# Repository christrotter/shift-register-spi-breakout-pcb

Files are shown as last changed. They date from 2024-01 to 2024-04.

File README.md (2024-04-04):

# Overview
Tested and working as of 20240403! \o/

A simple? breakout board that provides 32 matrix pins (_16 row and 16 column_) over SPI - using only 6 MCU pins!
Designed for and tested in QMK - requires a custom matrix.  Expects you to be using ROW2COL diode orientation.

This document includes:
- Understanding shift registers (_rather extensive_)
- Matrix-inator PCB notes
- Matrix-inator schematic detail
- Sample code

There's also a [STEP file](/matrix-inator-rev2.step) for testing fitment on your models.

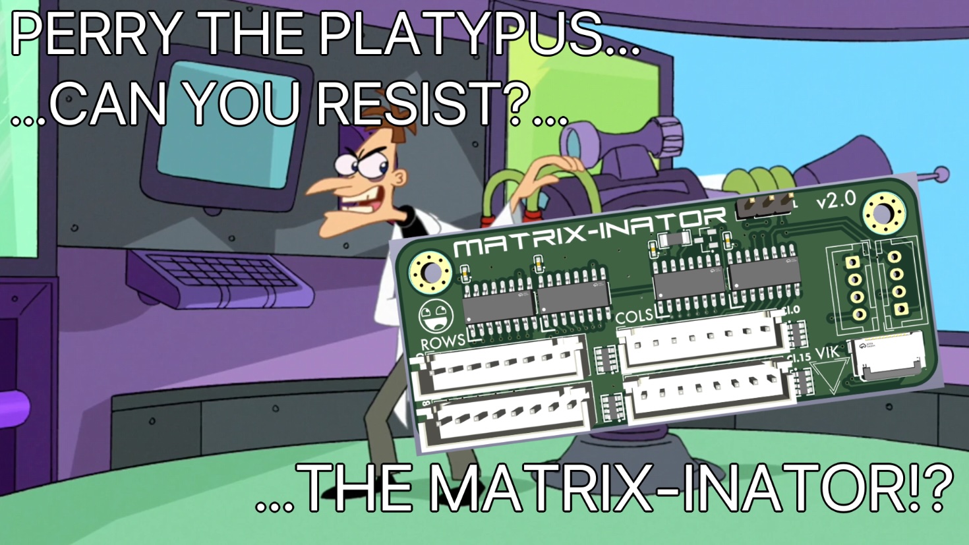
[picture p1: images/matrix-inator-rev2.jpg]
Perry...Perry the platypus?!

*-inate your keyboard matrix with the Matrix-inator!*

# Implementation notes
- The code examples are QMK-centric and utilize Chibios bits and bobs
- The latch header is redundant - **should always be connected ("enable latch")**.  If there's a future rev I will remove it.

# Why not 74HC165 shift registers?
There are 74HC589 supply issues, why not use the 74HC165 shift register?  Because *the 165 cannot share the SPI bus*, and QMK only allows you - at present - to utilize a single SPI bus.  You could use the 165 if you also included a tri-state buffer (e.g. 74HC1G125-Q100).  The 589 has that built-in.

# Usage
After soldering/hooking this into your keyboard, you'll need to add the custom matrix code to your QMK keyboard.

Between the [QMK docs](https://docs.qmk.fm/#/custom_matrix?id=custom-matrix) and this readme, you should have enough to get off the ground.

#### Connection
You can use the included 2x4 2.54mm pin header arrangement (_fits up to JST-XH headers_), or a [VIK-format 12-pin@0.5mm pitch FPC cable](https://github.com/sadekbaroudi/vik)
- _Power_: GND, 3.3V
- _Any GPIO_: Row CS, Col CS, Latch
- _SPI_: Clock/MISO/MOSI from the same SPI bus
- _rows and cols_: 2.54mm headers, do what you want here.

#### PCBA (PCB assembly)
If you want to order this, the gerbers are included in the latest [Github release](https://github.com/christrotter/shift-register-spi-breakout-pcb/releases/latest).

I seem to recall there being a silly part showing up that shouldn't have been (_like a logo or something_), but everything important came through.

Headers not part of the BOM, only the complicated and fiddly stuff.

#### Additonal parts you'll need
See the latest [Github release](https://github.com/christrotter/shift-register-spi-breakout-pcb/releases/latest) if you need all the parts.
- (_optional_) some flavour of 2.54mm-spaced headers
- 12-pin @ 0.5mm pitch FPC cable of sufficient length and a keyboard with a VIK port
  - (_or_) 2x 4-pin 2.54mm headers
- M3 hardware or some way of mounting the pcb to your model

#### Latch header notes
There's a 3-pin header labeled **Enable Latch**.

> *It will need to have pins 2 & 3 connected for the latch to work.* 

This is a development leftover.  Future revisions will not have it.

# Understanding shift registers
In order to understand shift registers, it's very important to understand how QMK's matrix scanning works.  And, of course, to understand that, you need to read their docs:
- https://docs.qmk.fm/#/understanding_qmk
- https://docs.qmk.fm/#/how_keyboards_work
- https://docs.qmk.fm/#/how_a_matrix_works

This doc is my simplification of the topic.

> **NOTE**: for the sake of illustration, you can use the idea that HIGH = "pin has voltage" and LOW = "pin is grounded". 

## Matrix scanning, tl;dr: 
1. Start matrix scan
2. Loop over each row pin.  on each loop, set this row pin HIGH (_all others LOW_) and then check **ALL** col pins for a reciprocal HIGH.
3. Build a `new_matrix_maybe` object with the result of each row iteration
4. Compare `live_matrix` with `new_matrix_maybe` - if differences, replace `live_matrix` with `new_matrix_maybe`
5. End matrix scan loop
(_and now QMK does everything else_)

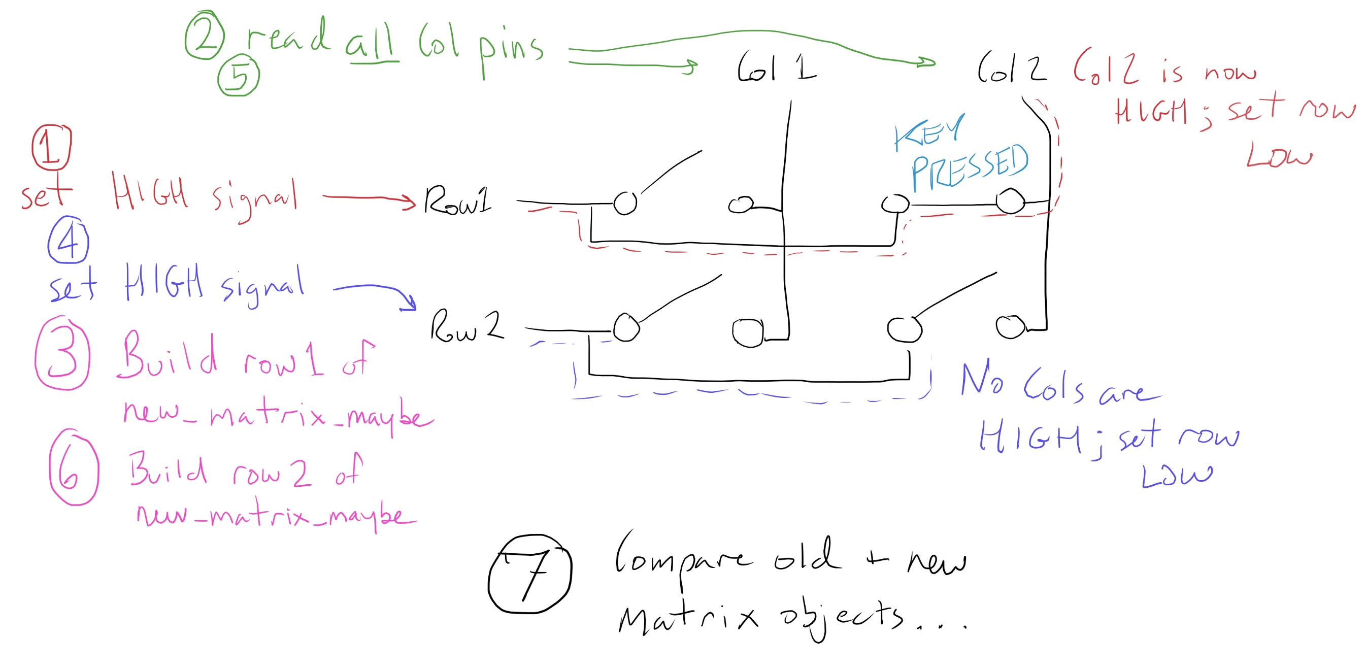
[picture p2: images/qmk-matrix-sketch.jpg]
Matrix basic


> Have you ever looked at the QMK console messages for 'scan rate'?  Well that number is how many times per second the above matrix scan runs (_simplifying_).

> **NOTE**: I use the term 'row pin' in this document only to keep things simple - QMK and shift registers don't work the same way as if you had GPIOs configured as row pins.

### why ROW2COL and not COL2ROW?
I have been working on integrating the Cyboard flex-pcb system into my latest build, and Cyboard is ROW2COL.  I'm sure the design could be refactored to handle any config method.  Indeed, if you use `direct pin` (_where the switches connect to ground_) you can have an even simpler shift register and matrix design.

If you're used to COL2ROW, it's, for all intents and purposes, identical, just flip rows & cols around.

## Pseudo matrix scan code
This is (_mostly_) not real code.
```c
bool matrix_scan_custom(matrix_row_t current_matrix[]) {
    static matrix_row_t temp_matrix[ROWS_COUNT] = {0};
    for (uint8_t row = 0; row < (ROWS_COUNT); row++) {
        set_row_high(row_pin);              // this row pin is set HIGH; any keypresses will show as HIGH on col pins
        cycle_latch_pin(latch_pin);         // prepares the col shift registers for data shipping; shift register magic
        col_state = spi_receive(col_pin);   // ship col state from shift register into the MCU as col_state
        new_matrix_maybe[row] = col_state;  // update this row of the new_matrix_maybe object with the returned col state
    }
    bool matrix_has_changed = compare_matrix(new_matrix_maybe, live_matrix);
    if (matrix_has_changed) {
        update_active_matrix(new_matrix_maybe);
    }
    return matrix_has_changed;
}
```

## Shift register magic explained
> Obviously shift registers are not magic and are completely understandable - I use the word 'magic' as an entertaining literary device.  Covering all of the detail is just too much scope for this doc.  If I can understand it, you can, too!

There are two types of registers being used here:
- 74HC589: get the HIGH/LOW state of the data pins and return via SPI ([74HC589 datasheet](https://www.onsemi.com/pdf/datasheet/mc74hc589a-d.pdf))
- 74HC595: set the data pins to a HIGH/LOW state as per instructions sent via SPI ([74HC595 datasheet](https://www.onsemi.com/pdf/datasheet/mc74hc595a-d.pdf))

The shift registers each have 8 "data" pins and a bunch of SPI/functionality pins.  
- The 589 reads 8 bits of data from the data pins in parallel, and then ships them out serially.
- The 595 takes 8 bits of data serially and applies it to the data pins in parallel.

Said another way, one accepts data from our code (_595_), the other provides data for our code (_589_).

Remember that there are no perfect solutions, and you're always making tradeoffs.  Recall we have a GPIO constraint...the shift registers get us more "GPIO" at the cost of complication.  That complication comes in the form of a parallel->serial->parallel flow.

- "Hay, row_shift_register, set a row pin to HIGH, please"
- "Okay, while that row is HIGH; col_shift_register, check all your pins - any HIGH?"
(_repeat for every row pin_)

Consider the matrix sketch above...instead of using GPIOs to send the signals to rows/cols, we use magical shift registers.

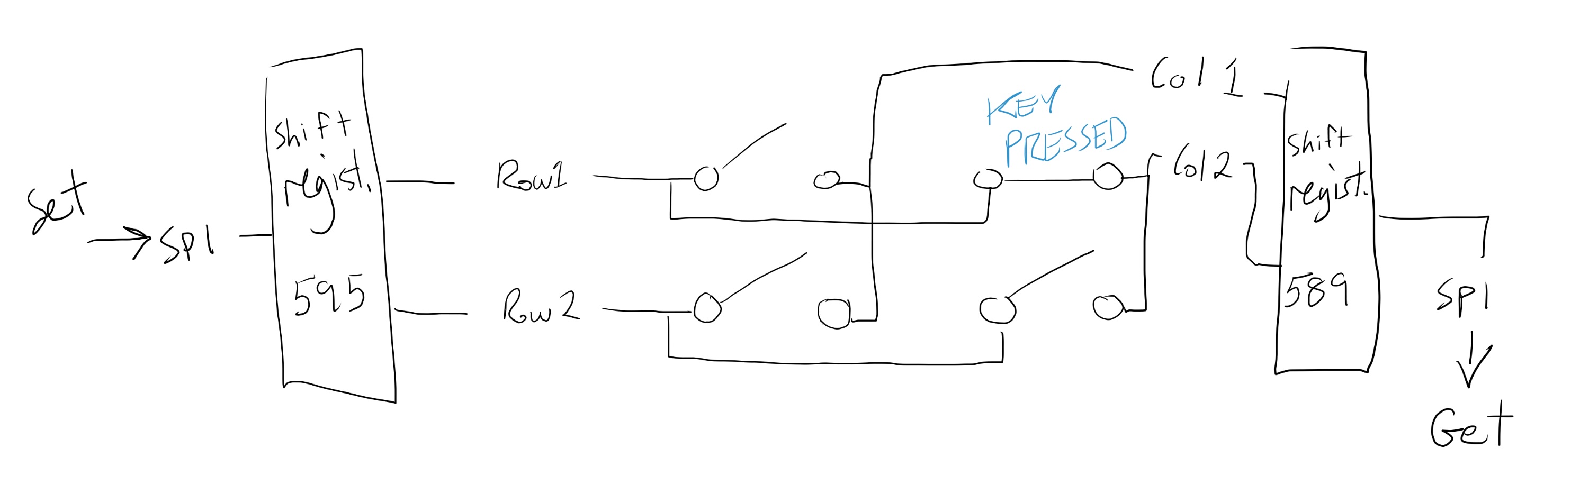
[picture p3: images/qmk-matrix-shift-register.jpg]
Matrix using shift registers


While there are some nuances for handling resets and the like - for keyboard applications you endlessly loop over rows, so no need for resets or anything fancy on the row_shift_registers.  But, the col_shift_registers handle ordered data...and if you handle the data incorrectly, your matrix results are sporadic at best.

So you need to understand a tiny bit about the 589 shift registers.

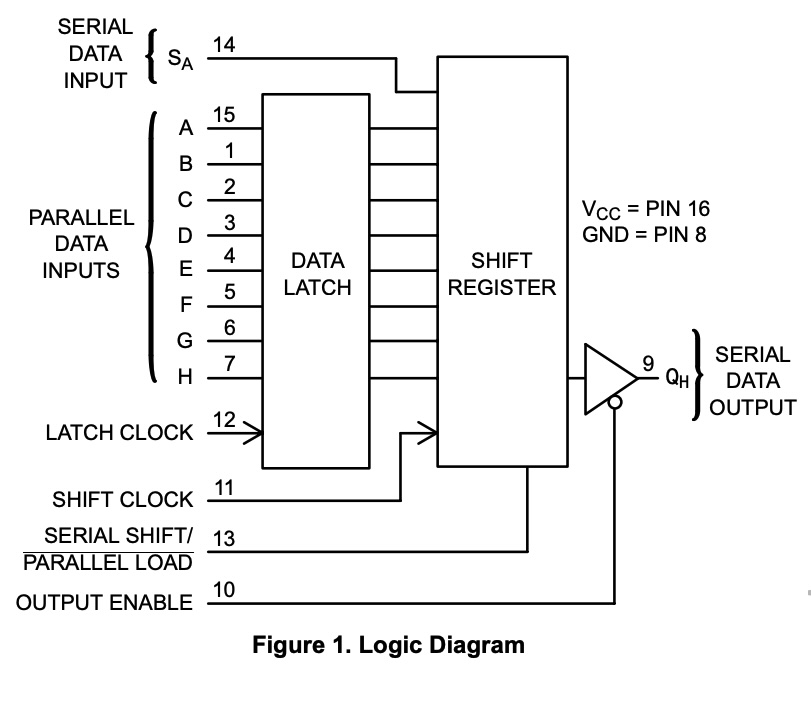
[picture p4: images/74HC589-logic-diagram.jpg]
Logic of 589


Simply put - the data we need is stored in the `data latch`.  To retrieve it via SPI, we need to tell the register to transfer it from the `data latch` into the `shift register`, which has a small amount of memory for serial operations.  Once in the next 'serial transfer' part of the clock cycling, the data in the `shift register` will be pulled out over SPI.

> Remember, the 595 works on effectively the same principles, just the reverse flow.

### Deep magicks
Each shift register has 8 bits (_1 byte_) - the data pins are digital, 0 or 1 - so you can understand what is going on in your digital matrix (_HIGH/LOW_) by polling your shift registers with sets/gets (_layman's terms_).

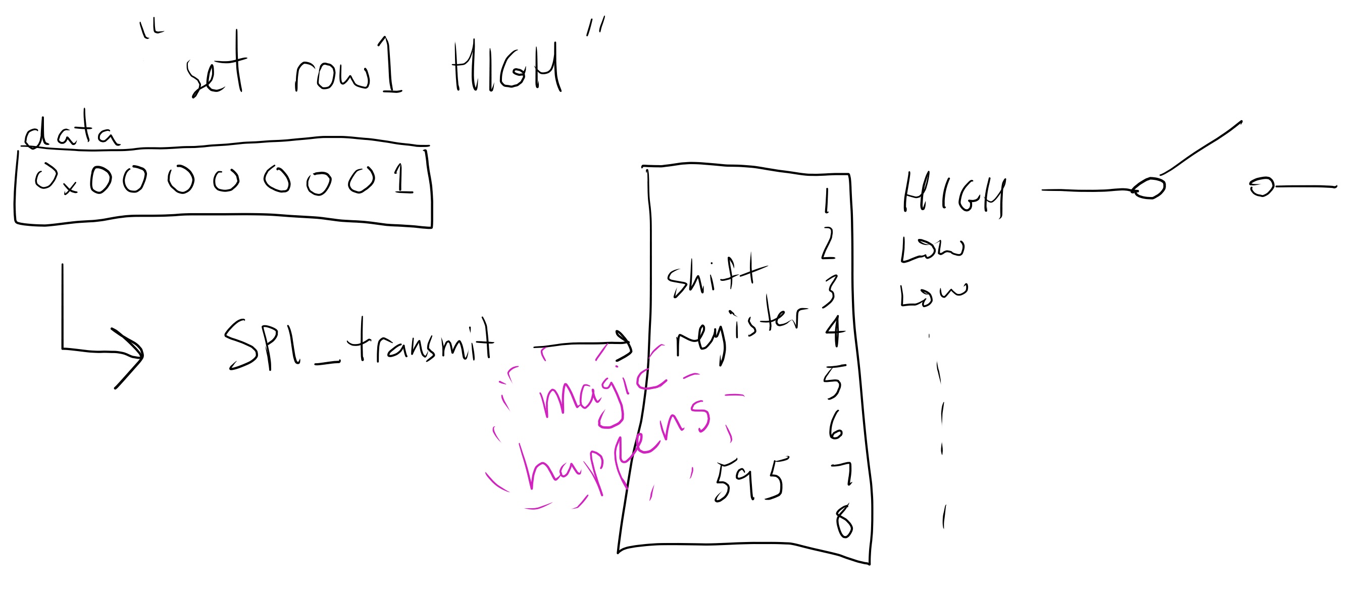
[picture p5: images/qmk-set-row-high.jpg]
Shift register magic


### for each row pin
> **NOTE**: CS pins on registers are normally HIGH.  You set them LOW to activate them.

> **NOTE**: The flow graphics illustrate how a 589 register works.  A 595 is exactly the same picture, just mirrored.

1. Set `row_cs` LOW; the rows register is now the active SPI device
2. Send the data packet telling the register which pin to set HIGH (`spi_transmit`)
3. Set `row_cs` HIGH; we are done with the rows register, so de-select it
4. Set the `latch` HIGH; the 589 register transfers current pin data from latch to register
5. Set the `latch` LOW; register cannot do data transfer while latch is HIGH
6. Set the `col_cs` LOW - the register will start transferring data over SPI
7. Get the data packet that will tell us which col pin is HIGH (`spi_receive`)
8. Set the `col_cs` HIGH - we are done with the cols register, so de-select it

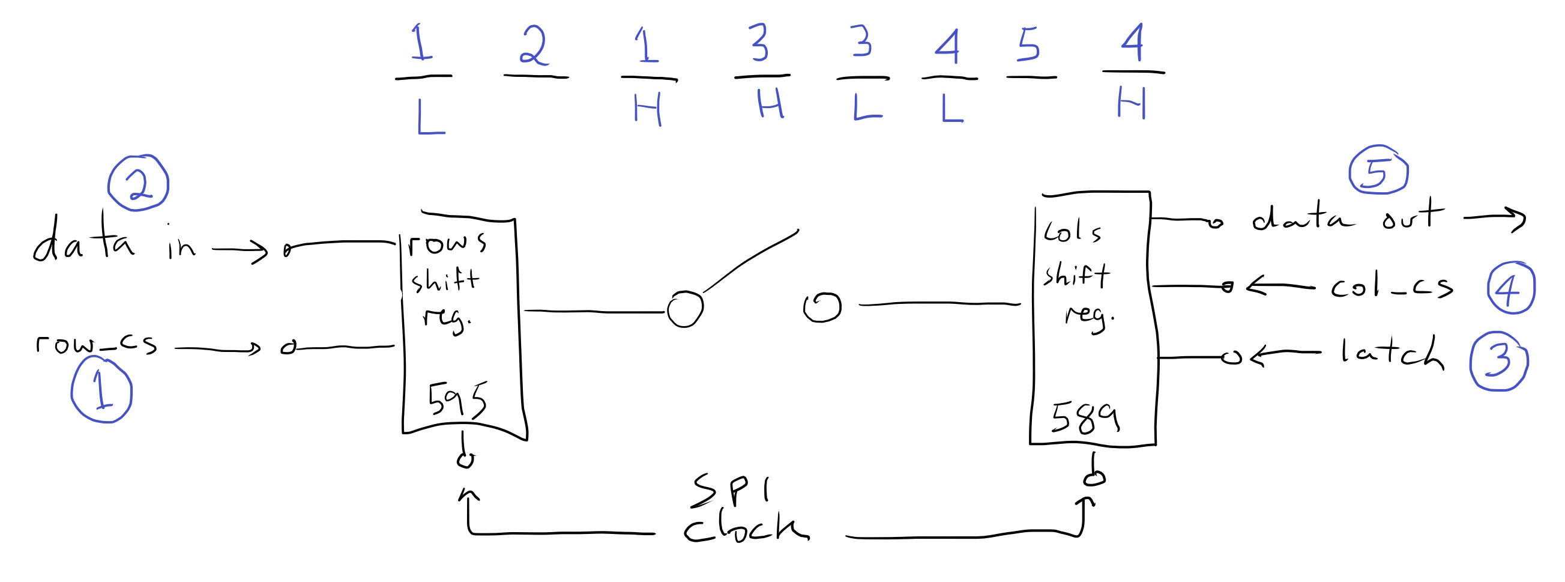
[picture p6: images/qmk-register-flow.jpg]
Shift register flow


And now consider the 589 data flow mentioned above...

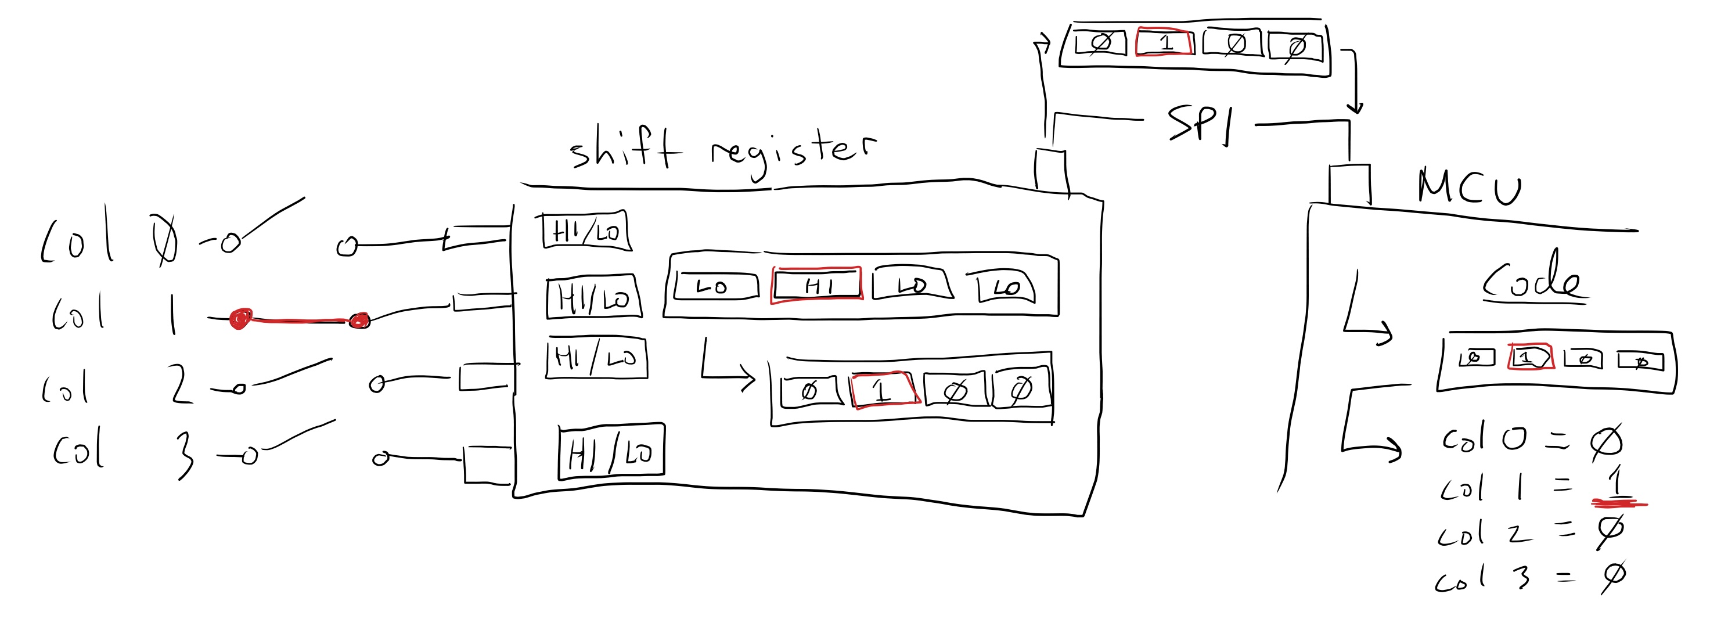
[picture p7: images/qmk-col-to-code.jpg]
Register data basic


## even more depth
...is something I won't get into.  Suffice to say that the registers function with a lot of clock timing and conditions available based on what is HIGH and what is LOW.

The matrix code, Kicad files, and part datasheets provide the rest of the puzzle.

A very important feature of the design are the 10k resistor arrays/networks that pull down the col pins to ground.  If you fail to implement this you will get super random/repeating responses.  How do I know this?

### it's complicated
The order of operations is determined by the timing diagram.  That sentence makes me sound like an elite who knows more than you.  _lies.  deception._

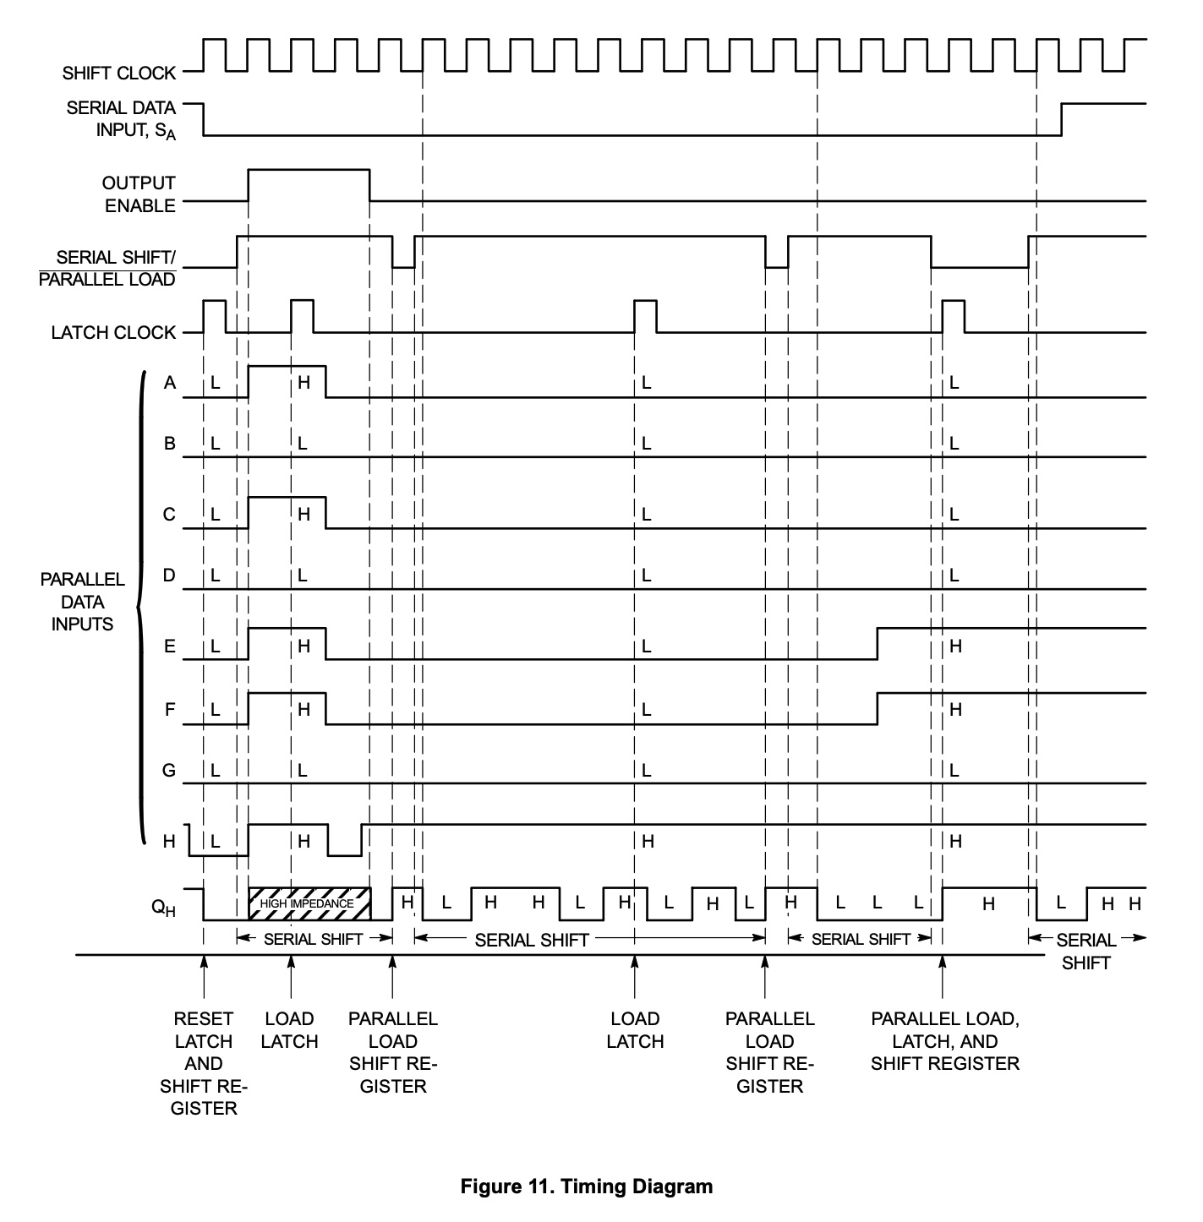
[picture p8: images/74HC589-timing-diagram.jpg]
Timing of 589


# Matrix-inator notes
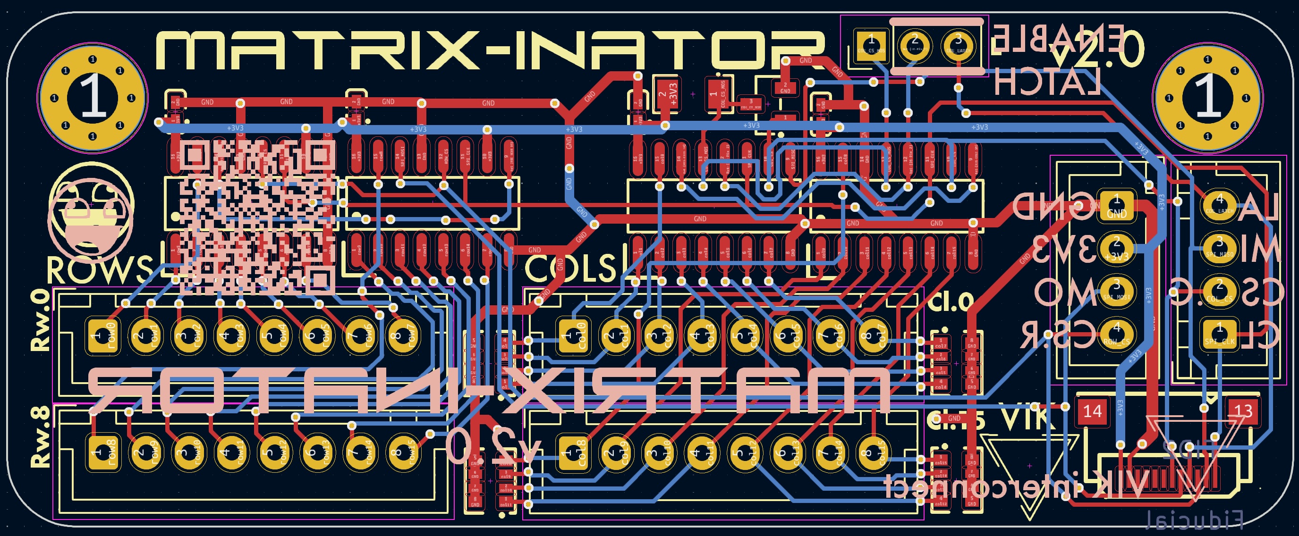
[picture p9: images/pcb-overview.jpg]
PCB overview

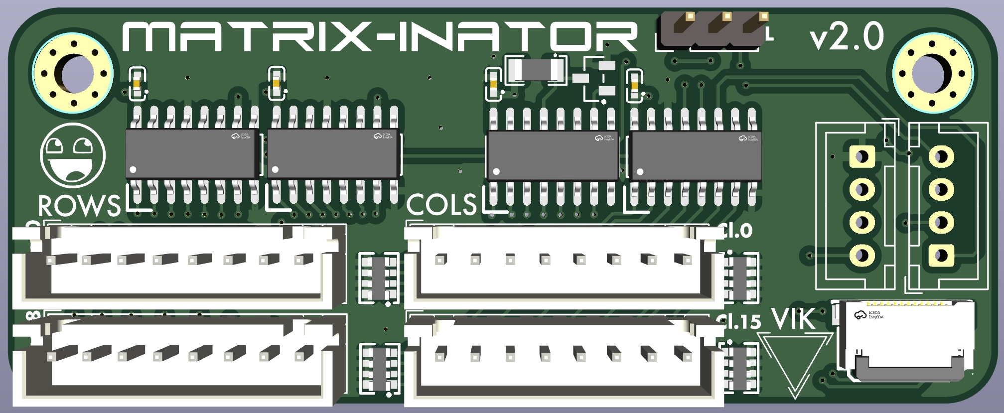
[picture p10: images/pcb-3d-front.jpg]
3D render - front

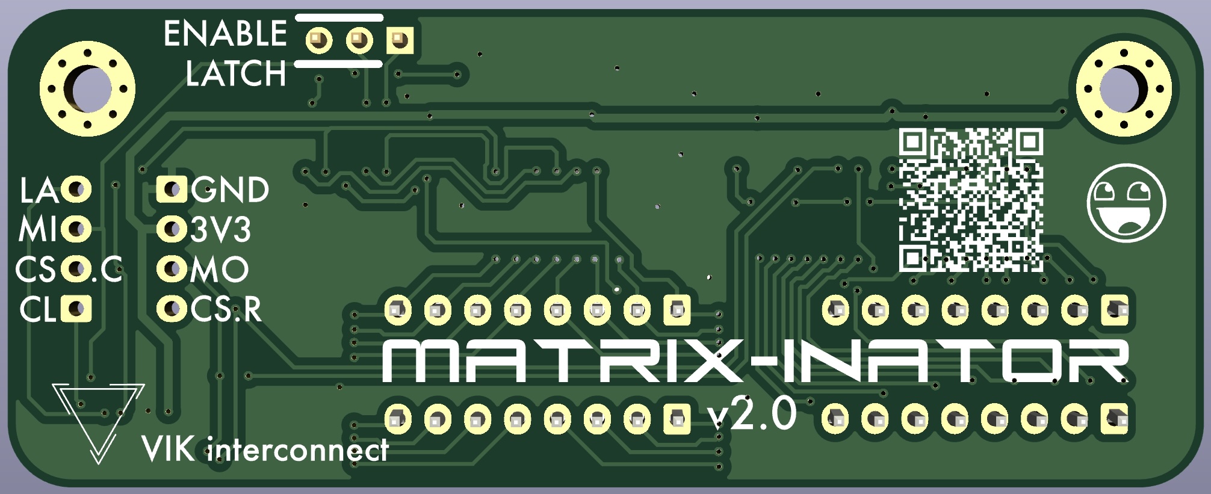
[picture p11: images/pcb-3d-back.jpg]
3D render - back


## For the DIY-er
If you want to incorporate shift registers into your PCB, highly advise you do the following...
- Read the datasheets, carefully, twice, then thrice.
- Remember that pcb manufacturers have tolerances.  Abide by them and err on the generous side.
- The pull-down effect of the 10k resistor network is non-negotiable.  Floating signal is a guarantee, not a maybe.  Floating signal means your board does not work.
- Remember that decoupling caps need to be as close as possible to their device, and the current should flow through the cap trace into the device.

## Performance
It's worth noting that if you use the full 16 rows you will not have a very performant keyboard - scan rate drops to **1100**.  Still usable as a keyboard, but you won't have a ton of CPU overhead for other features.

## PCB details
- M3 mounts; 65mm center-to-center
- The shift registers are only available as extended parts from JLC (_extra fees_)
- 2.54mm spacing on all pin footprints
- Row/col pins designed for 4x 8-pin JST-XH 2.54 headers
- Normal 2.54mm pin headers also work fine
- Two-layer board; ground pour on both sides tied together with vias

## VIK module certification

| Category | Classification | Response |
| --- | --- | --- |
| FPC connector | Required | :heavy_check_mark: |
| Breakout pins | Recommended | :heavy_check_mark: |
| Uses: SPI | Optional | :heavy_check_mark: |
| SPI used for SPI only | Strongly recommended | :heavy_check_mark: |
| Uses: I2C | Optional | :x: |
| I2C used for I2C only | Strongly Recommended | :x: |
| I2C pull ups | Required | N/A |
| Uses: RGB | Optional | :x: |
| Uses: Extra GPIO 1 | Optional | :heavy_check_mark: |
| Uses: Extra GPIO 2 | Optional | :heavy_check_mark: |
| Standard PCB Size/Mount | Strongly recommended | :x: |

## Pins
- ROW_CS - trigger to enable sending bits to the Row 74HC595 shift registers
- COL_CS - trigger enable reading bits from the Col 74HC589 shift registers
- LATCH_CS - trigger to prep all Col 74HC589 shift registers for data retrieval
- SPI: crucial that you use SPI pins on the same SPI bus
  - Clock: all SPI devices need this
  - MOSI: ROW shift registers are sent data from the MCU
  - MISO: COL shift registers return data to the MCU
- 3V3, GND - expects +3.3v and a ground

## Schematics
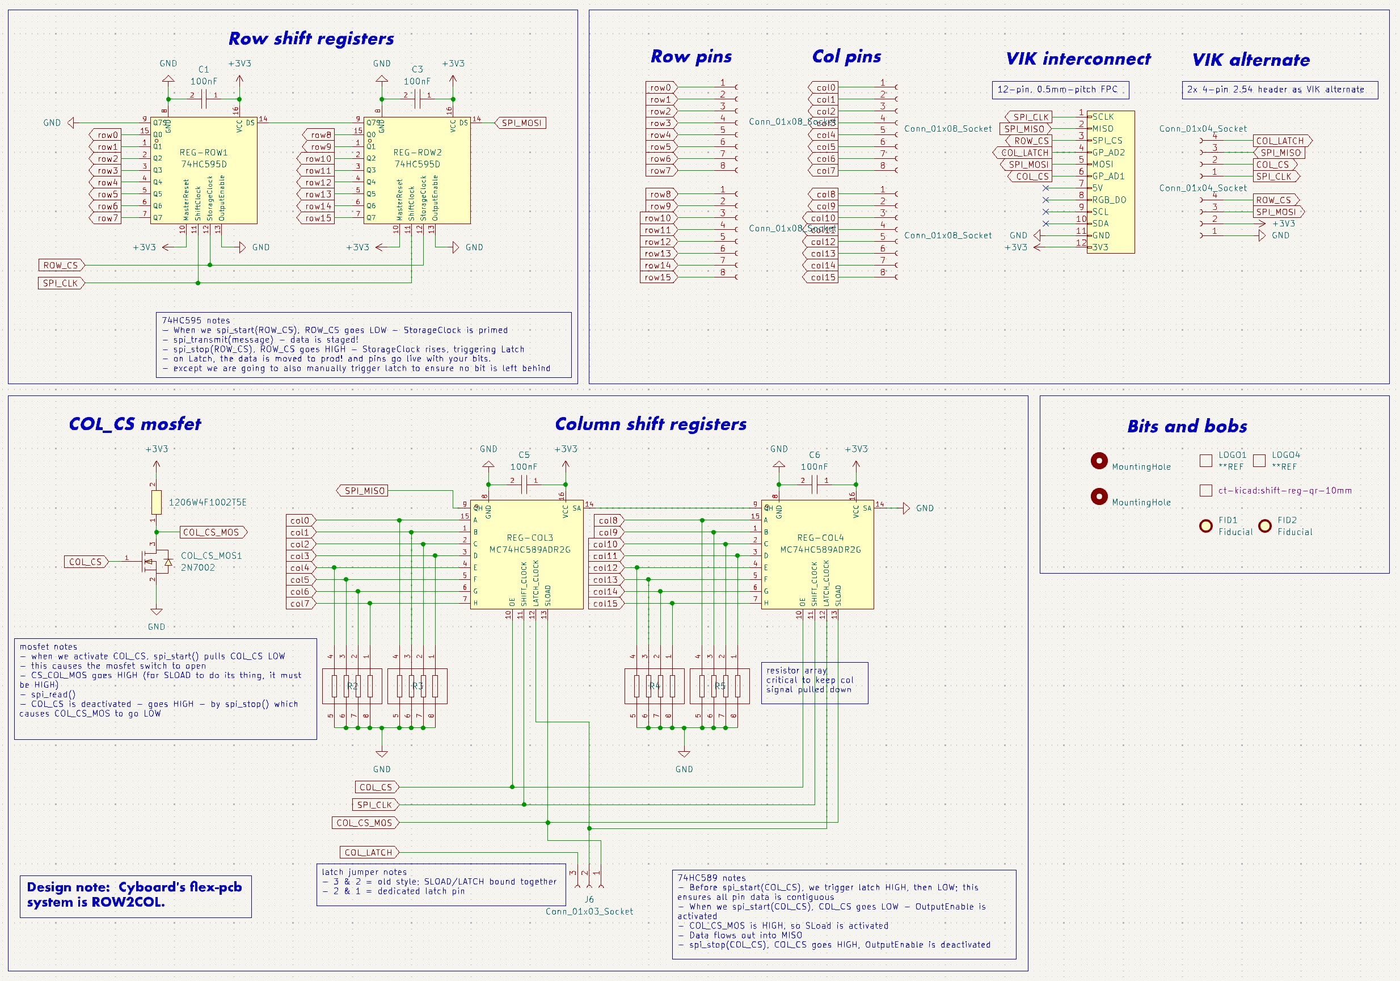
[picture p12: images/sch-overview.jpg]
Schematic overview

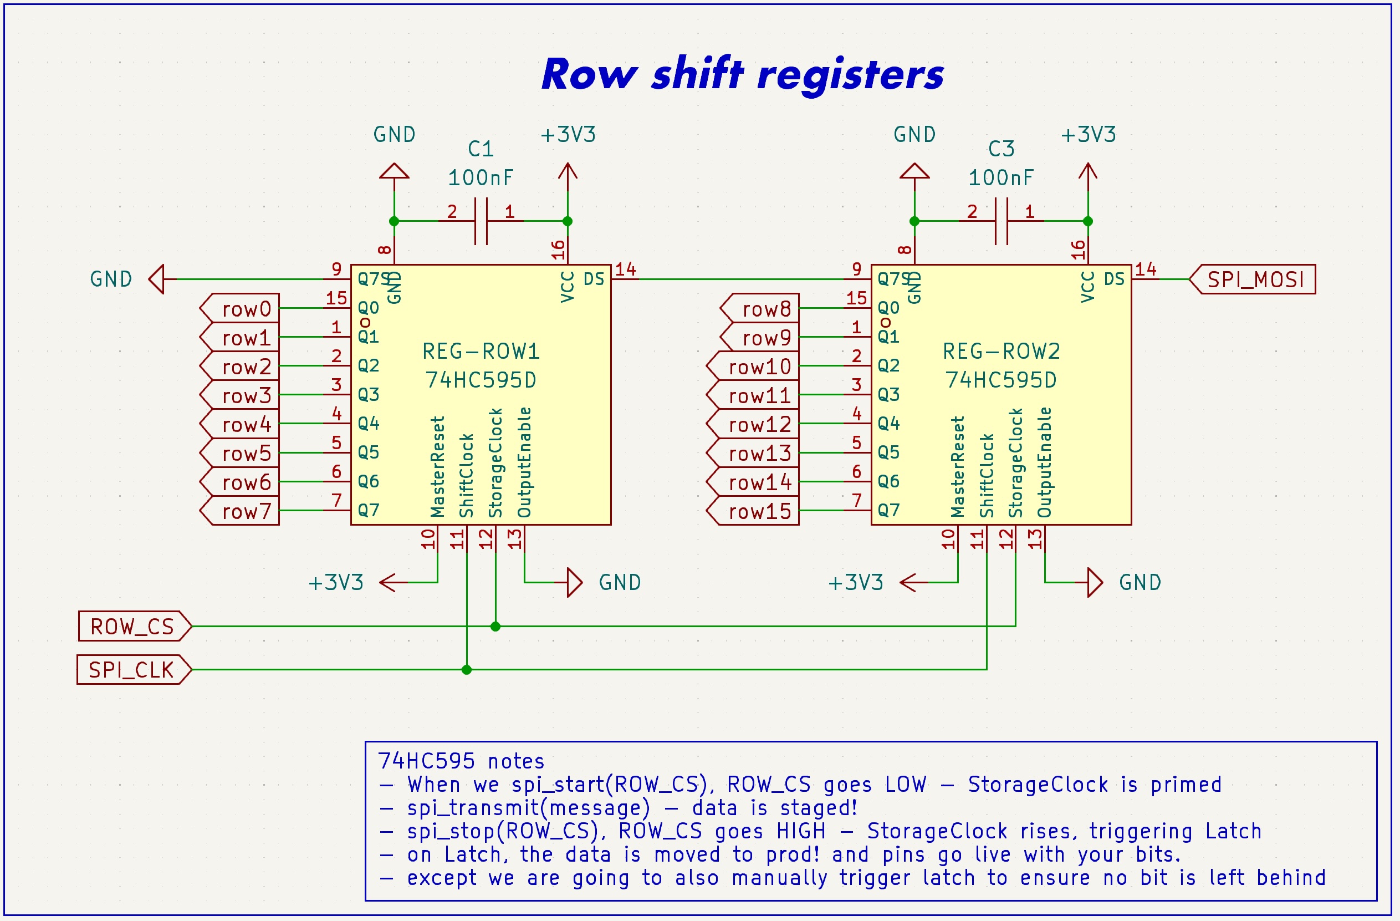
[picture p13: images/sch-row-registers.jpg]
Schematic - row registers detail

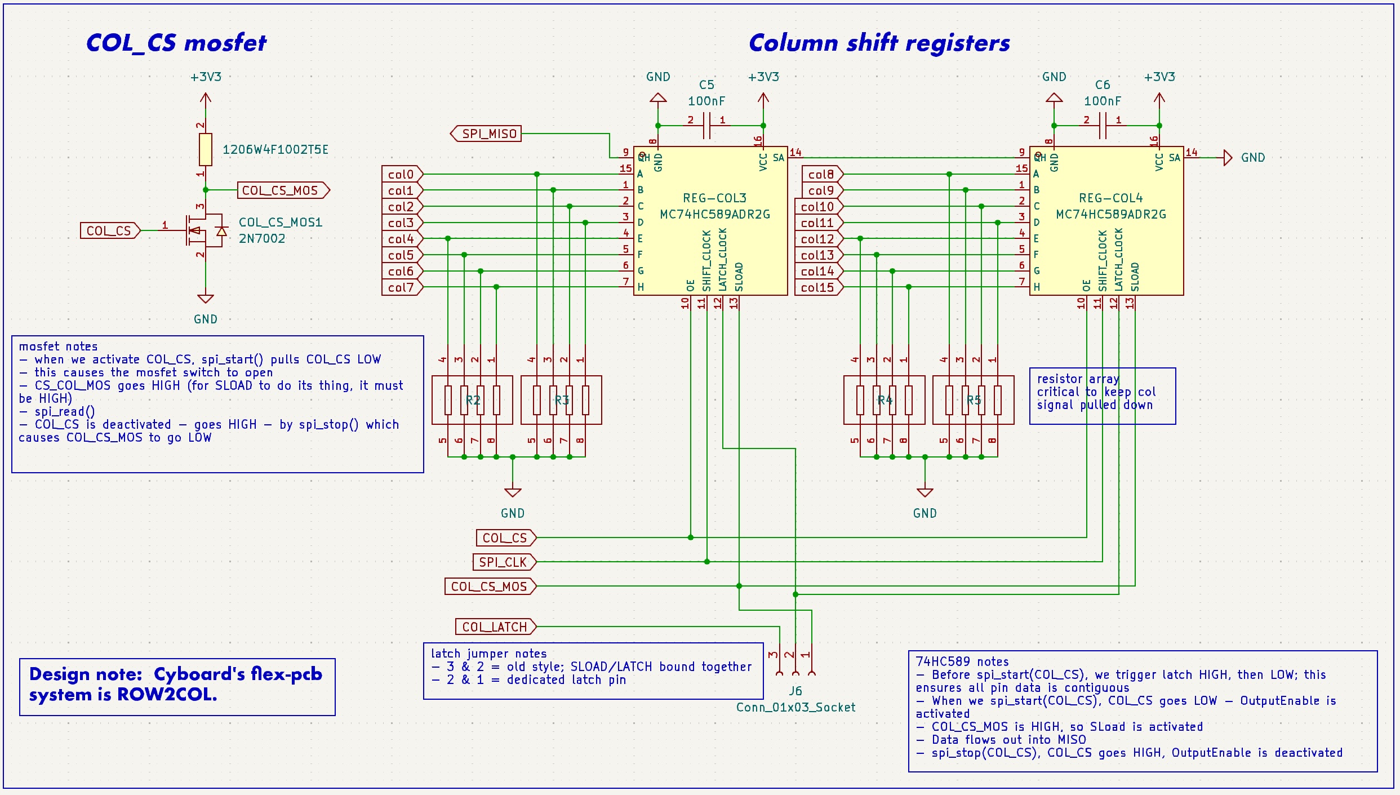
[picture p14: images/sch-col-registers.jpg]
Schematic - col registers detail


# Sample code
This will undoubtedly get improved, but this is enough to get you off the ground and using the Matrix-inator.

## info.json
Bits you'll need in `keyboard/info.json`:
```json
    "diode_direction": "ROW2COL",
    "matrix_pins": {
        "custom_lite": true,
        "rows": ["NO_PIN", "NO_PIN", "NO_PIN", "NO_PIN", "NO_PIN", "NO_PIN"],
        "cols": ["NO_PIN", "NO_PIN", "NO_PIN", "NO_PIN", "NO_PIN", "NO_PIN", "NO_PIN", "NO_PIN", "NO_PIN", "NO_PIN", "NO_PIN"]
      },
    "layouts": {
        "LAYOUT": {
            "layout": [
                {"matrix": [5, 0], "x": 0, "y": 0},
                {"matrix": [5, 1], "x": 1, "y": 0},
                etc
        }
    },
```

## config.h
Bits you'll need in `keyboard/config.h`:

For figuring out which SPI GPIO to use, section 1.4.3 here: https://datasheets.raspberrypi.com/rp2040/rp2040-datasheet.pdf
```c
// SPI configuration
#define SPI_MATRIX_DIVISOR 16
#define SPI_MODE 0
#define SPI_DRIVER SPID1 // you might change this
// GPIO config for main SPI config needs to match up with the SPI bus you are using
#define SPI_SCK_PIN  GPxx // e.g. SPI0 SCK
#define SPI_MOSI_PIN GPxx // e.g. SPI0 TX (Master Out, Slave In)
#define SPI_MISO_PIN GPxx // e.g. SPI0 RX (Master In, Slave Out)
// GPIO config for CS/latch pins can be any GPIO
#define SPI_MATRIX_LATCH_PIN GPxx
#define SPI_MATRIX_CHIP_SELECT_PIN_ROWS GPxx
#define SPI_MATRIX_CHIP_SELECT_PIN_COLS GPxx
// custom matrix config
#define MATRIX_COLS_SHIFT_REGISTER_COUNT 2
#define MATRIX_ROWS_SHIFT_REGISTER_COUNT 2
#define ROWS_COUNT 12 // this can be replaced w. array_size or something?
#define ROWS { \
    0b0000000000000001, \
    0b0000000000000010, \
    0b0000000000000100, \
    0b0000000000001000, \
    0b0000000000010000, \
    0b0000000000100000, \
    0b0000000001000000, \
    0b0000000010000000, \
    0b0000000100000000, \
    0b0000001000000000, \
    0b0000010000000000, \
    0b0000100000000000, \
} // this makes up the magic of the 'message' we send to the 595 register
```

## rules.mk
For `keyboard/rules.mk`:
```
SRC += matrix.c
```

## halconf.h
Bits you'll need in `keyboard/halconf.h`:

```c
#define HAL_USE_SPI TRUE
#define SPI_USE_WAIT TRUE
#define SPI_SELECT_MODE SPI_SELECT_MODE_PAD
```

## mcuconf.h
Bits you'll need in `keyboard/mcuconf.h`:

You might use SPI0?
```c
#undef RP_SPI_USE_SPI1
#define RP_SPI_USE_SPI1 TRUE
```

## matrix.c
This file goes in: `keyboard/keymap/map/` (_I think it might actually be meant to go in the keymap dir?_)

Actual working code.  (_mostly tested as of this writing_)
```c
// Copyright 2018-2022 Nick Brassel (@tzarc)
// Copyright 2020-2023 alin m elena (@alinelena, @drFaustroll)
// Copyright 2023 Stefan Kerkmann (@karlk90)
// Copyright 2023 (@burkfers)
// SPDX-License-Identifier: GPL-3.0-or-later

#include "quantum.h"
#include "spi_master.h"

static const uint16_t row_values[ROWS_COUNT] = ROWS;
static const pin_t latch_pin = SPI_MATRIX_LATCH_PIN;

void matrix_init_custom(void) {
    setPinOutput(SPI_MATRIX_CHIP_SELECT_PIN_COLS);
    writePinHigh(SPI_MATRIX_CHIP_SELECT_PIN_COLS);
    setPinOutput(SPI_MATRIX_CHIP_SELECT_PIN_ROWS);
    writePinHigh(SPI_MATRIX_CHIP_SELECT_PIN_ROWS);
    setPinOutput(latch_pin);
    writePinLow(latch_pin);
    spi_init();
}

static inline void write_to_rows(uint16_t value) {
    uint8_t message[2] = {(uint8_t)(value & 0xFF), (value >> 8) & 0xFF}; // cut 0xABCD into {0xAB, 0xCD}
    spi_start(SPI_MATRIX_CHIP_SELECT_PIN_ROWS, true, SPI_MODE, SPI_MATRIX_DIVISOR);
    spi_transmit(message, 2);
    spi_stop();
}

// /**
//  * @brief Helper function to wait until a pin  has reached the wanted target
//  * state. This only works for Push-Pull pins with enabled input stage.
//  */
static void __time_critical_func(write_and_wait_for_pin)(pin_t pin, uint8_t target_state) {
    writePin(pin, target_state);
    rtcnt_t start = chSysGetRealtimeCounterX();
    rtcnt_t end   = start + MS2RTC(REALTIME_COUNTER_CLOCK, 20);
    while (chSysIsCounterWithinX(chSysGetRealtimeCounterX(), start, end)) {
        if (readPin(pin) == target_state) {
            return;
        }
    }
}

bool matrix_scan_custom(matrix_row_t current_matrix[]) {
    static matrix_row_t temp_matrix[ROWS_COUNT] = {0};
    
    for (uint8_t row = 0; row < (ROWS_COUNT); row++) {
        uint8_t temp_col_receive[MATRIX_COLS_SHIFT_REGISTER_COUNT] = {0};
        uint16_t temp_col_state;

        write_to_rows(row_values[row]);

        // get the shift registers to move data from latch to register
        write_and_wait_for_pin(latch_pin, 1);
        write_and_wait_for_pin(latch_pin, 0);

        // read the cols shift register contents over serial
        spi_start(SPI_MATRIX_CHIP_SELECT_PIN_COLS, true, SPI_MODE, SPI_MATRIX_DIVISOR);
        spi_receive((uint8_t*)temp_col_receive, MATRIX_COLS_SHIFT_REGISTER_COUNT);
        spi_stop();

        temp_col_state = temp_col_receive[0] | (temp_col_receive[1] << 8);
        temp_matrix[row] = temp_col_state;
    }
    bool matrix_has_changed = memcmp(current_matrix, temp_matrix, sizeof(temp_matrix)) != 0;
    if (matrix_has_changed) {
        memcpy(current_matrix, temp_matrix, sizeof(temp_matrix));
    }
    return matrix_has_changed;
}
```

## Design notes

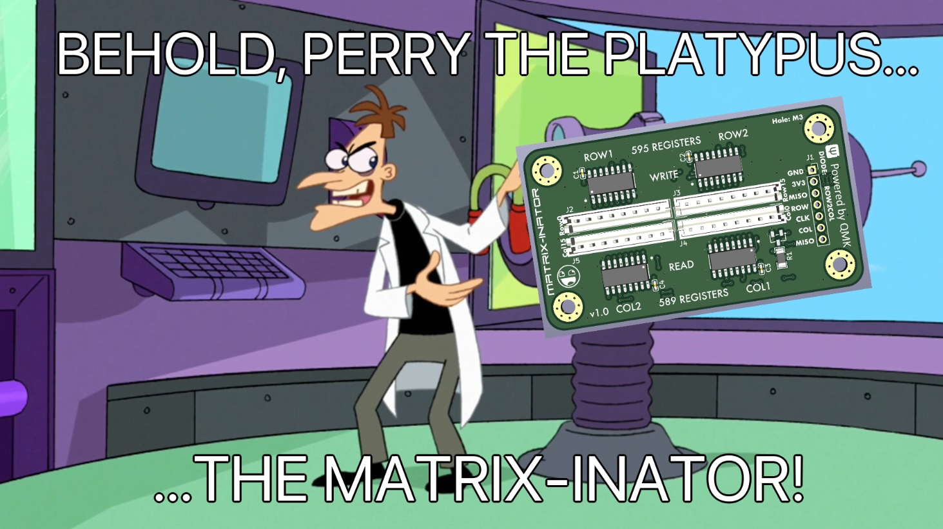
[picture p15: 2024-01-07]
images/matrix-inator-rev1.jpg

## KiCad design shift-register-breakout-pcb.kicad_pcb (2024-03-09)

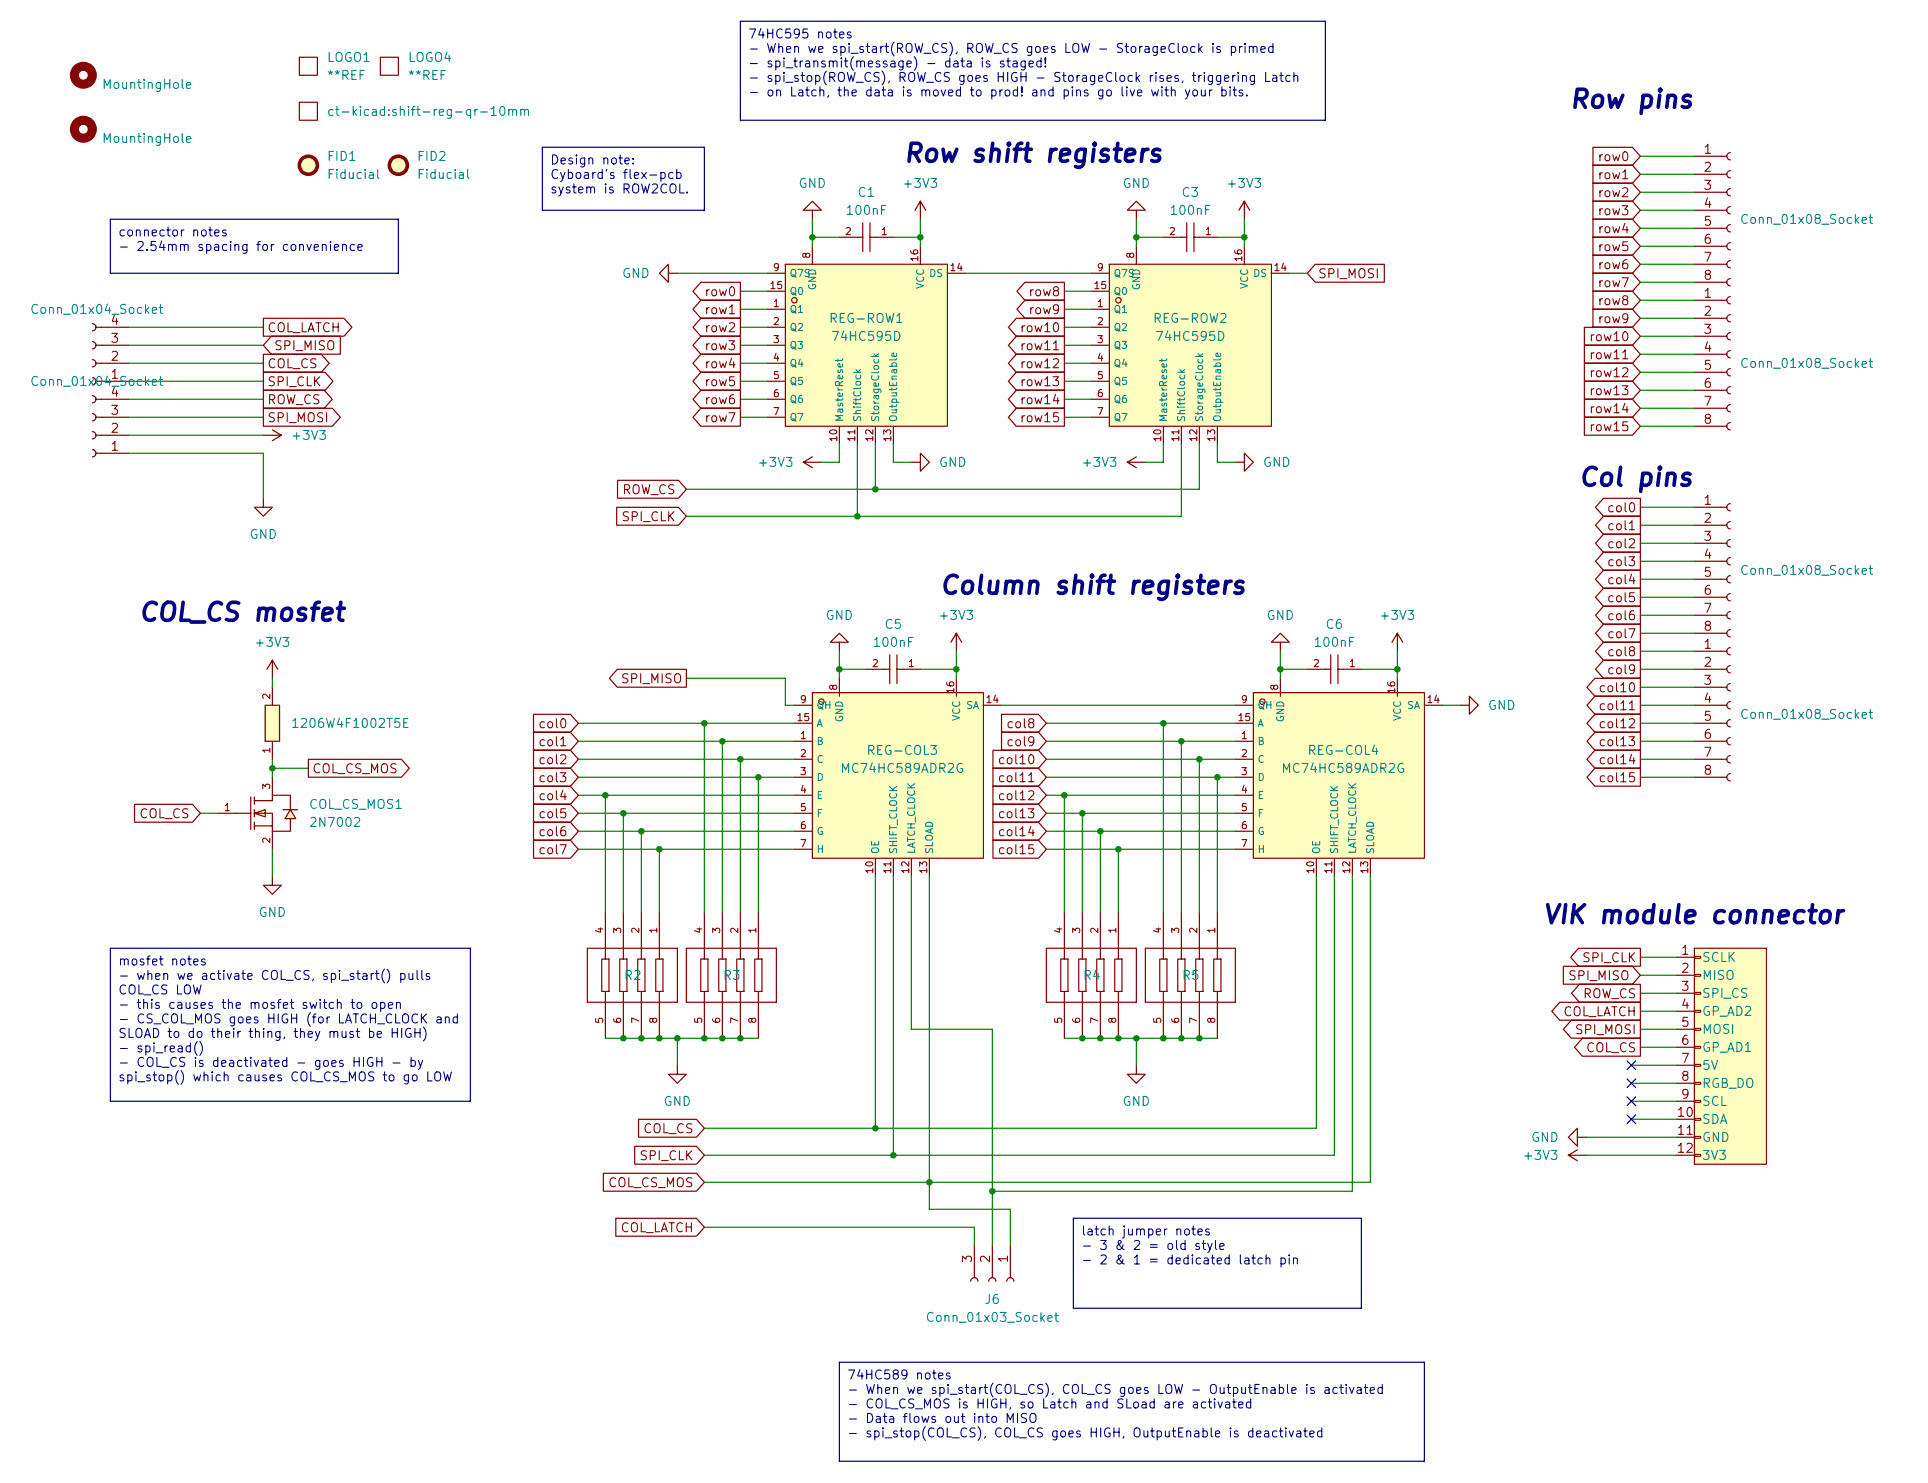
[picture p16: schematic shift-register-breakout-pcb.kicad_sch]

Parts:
C1, C3, C5, C6: 100nF; C0402; LCSC C1525
COL_CS_MOS1: 2N7002; SOT-23-3_L2.9-W1.3-P1.90-LS2.4-BR; LCSC C8545
FID1, FID2: Fiducial; vik-logo-small
H1, H2: MountingHole; MountingHole_3mm_Pad_Via
J1, J8: Conn_01x04_Socket; JST_XH_B4B-XH-A_1x04_P2.50mm_Vertical
J2, J3, J4, J5: Conn_01x08_Socket; JST_XH_B8B-XH-A_1x08_P2.50mm_Vertical
J6: Conn_01x03_Socket; PinHeader_1x03_P2.54mm_Vertical
J7: vik-module-connector; FPC-SMD_XF2M-1215-1AH
LOGO1, LOGO4: **REF; awesome-logo
LOGO2: **REF; shift-reg-qr-10mm
R1: 1206W4F1002T5E; R1206; LCSC C17902
R2, R3, R4, R5: 4D03WGJ0103T5E; RES-ARRAY-SMD_0603-8P-L3.2-W1.6-BL; LCSC C29718
REG-COL3, REG-COL4: MC74HC589ADR2G; SOIC-16_L9.9-W3.9-P1.27-LS6.0-BL; LCSC C7343
REG-ROW1, REG-ROW2: 74HC595D; SOIC-16_L9.9-W3.9-P1.27-LS6.0-BL; LCSC C5947

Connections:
+3V3: C1.1, C3.1, C5.1, C6.1, J7.12 (3V3), J8.2, R1.2, REG-COL3.16 (VCC), REG-COL4.16 (VCC), REG-ROW1.10 (MasterReset), REG-ROW1.16 (VCC), REG-ROW2.10 (MasterReset), REG-ROW2.16 (VCC)
COL_CS: COL_CS_MOS1.1 (G), J1.2, J7.6 (GP_AD1), REG-COL3.10 (OE), REG-COL4.10 (OE)
COL_CS_MOS: COL_CS_MOS1.3 (D), J6.1, R1.1, REG-COL3.13 (SLOAD), REG-COL4.13 (SLOAD)
COL_LATCH: J1.4, J6.3, J7.4 (GP_AD2)
GND: C1.2, C3.2, C5.2, C6.2, COL_CS_MOS1.2 (S), J7.11 (GND), J8.1, R2.5, R2.6, R2.7, R2.8, R3.5, R3.6, R3.7, R3.8, R4.5, R4.6, R4.7, R4.8, R5.5, R5.6, R5.7, R5.8, REG-COL3.8 (GND), REG-COL4.8 (GND), REG-COL4.14 (SA), REG-ROW1.8 (GND), REG-ROW1.9 (Q7S), REG-ROW1.13 (OutputEnable), REG-ROW2.8 (GND), REG-ROW2.13 (OutputEnable)
unnamed: J6.2, REG-COL3.12 (LATCH_CLOCK), REG-COL4.12 (LATCH_CLOCK)
unnamed: REG-COL3.14 (SA), REG-COL4.9 (QH)
unnamed: REG-ROW1.14 (DS), REG-ROW2.9 (Q7S)
ROW_CS: J7.3 (SPI_CS), J8.4, REG-ROW1.12 (StorageClock), REG-ROW2.12 (StorageClock)
SPI_CLK: J1.1, J7.1 (SCLK), REG-COL3.11 (SHIFT_CLOCK), REG-COL4.11 (SHIFT_CLOCK), REG-ROW1.11 (ShiftClock), REG-ROW2.11 (ShiftClock)
SPI_MISO: J1.3, J7.2 (MISO), REG-COL3.9 (QH)
SPI_MOSI: J7.5 (MOSI), J8.3, REG-ROW2.14 (DS)
col0: J4.1, R3.4, REG-COL3.15 (A)
col1: J4.2, R3.3, REG-COL3.1 (B)
col2: J4.3, R3.2, REG-COL3.2 (C)
col3: J4.4, R3.1, REG-COL3.3 (D)
col4: J4.5, R2.4, REG-COL3.4 (E)
col5: J4.6, R2.3, REG-COL3.5 (F)
col6: J4.7, R2.2, REG-COL3.6 (G)
col7: J4.8, R2.1, REG-COL3.7 (H)
col8: J5.1, R5.4, REG-COL4.15 (A)
col9: J5.2, R5.3, REG-COL4.1 (B)
col10: J5.3, R5.2, REG-COL4.2 (C)
col11: J5.4, R5.1, REG-COL4.3 (D)
col12: J5.5, R4.4, REG-COL4.4 (E)
col13: J5.6, R4.3, REG-COL4.5 (F)
col14: J5.7, R4.2, REG-COL4.6 (G)
col15: J5.8, R4.1, REG-COL4.7 (H)
row0: J2.1, REG-ROW1.15 (Q0)
row1: J2.2, REG-ROW1.1 (Q1)
row2: J2.3, REG-ROW1.2 (Q2)
row3: J2.4, REG-ROW1.3 (Q3)
row4: J2.5, REG-ROW1.4 (Q4)
row5: J2.6, REG-ROW1.5 (Q5)
row6: J2.7, REG-ROW1.6 (Q6)
row7: J2.8, REG-ROW1.7 (Q7)
row8: J3.1, REG-ROW2.15 (Q0)
row9: J3.2, REG-ROW2.1 (Q1)
row10: J3.3, REG-ROW2.2 (Q2)
row11: J3.4, REG-ROW2.3 (Q3)
row12: J3.5, REG-ROW2.4 (Q4)
row13: J3.6, REG-ROW2.5 (Q5)
row14: J3.7, REG-ROW2.6 (Q6)
row15: J3.8, REG-ROW2.7 (Q7)

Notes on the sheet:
mosfet notes - when we activate COL_CS, spi_start() pulls COL_CS LOW - this causes the mosfet switch to open - CS_COL_MOS goes HIGH (for LATCH_CLOCK and SLOAD to do their thing, they must be HIGH) - spi_read() - COL_CS is deactivated - goes HIGH - by spi_stop() which causes COL_CS_MOS to go LOW
74HC595 notes - When we spi_start(ROW_CS), ROW_CS goes LOW - StorageClock is primed - spi_transmit(message) - data is staged! - spi_stop(ROW_CS), ROW_CS goes HIGH - StorageClock rises, triggering Latch - on Latch, the data is moved to prod! and pins go live with your bits.
74HC589 notes - When we spi_start(COL_CS), COL_CS goes LOW - OutputEnable is activated - COL_CS_MOS is HIGH, so Latch and SLoad are activated - Data flows out into MISO - spi_stop(COL_CS), COL_CS goes HIGH, OutputEnable is deactivated
Design note: Cyboard's flex-pcb system is ROW2COL.
connector notes - 2.54mm spacing for convenience
latch jumper notes - 3 & 2 = old style - 2 & 1 = dedicated latch pin
Column shift registers
COL_CS mosfet
Col pins
Row pins
Row shift registers
VIK module connector

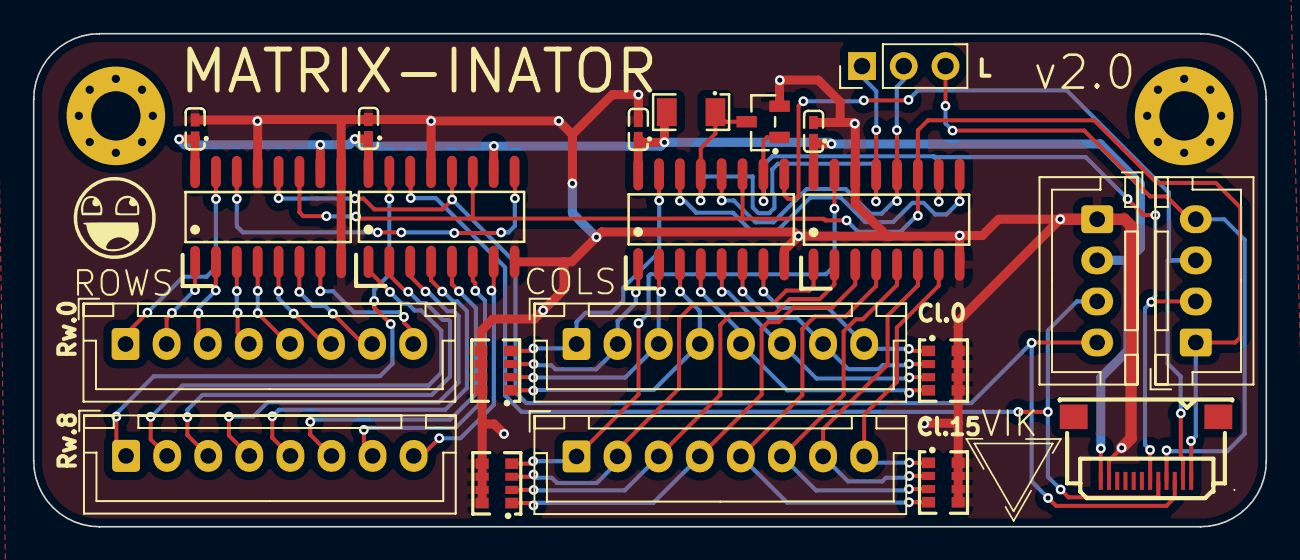
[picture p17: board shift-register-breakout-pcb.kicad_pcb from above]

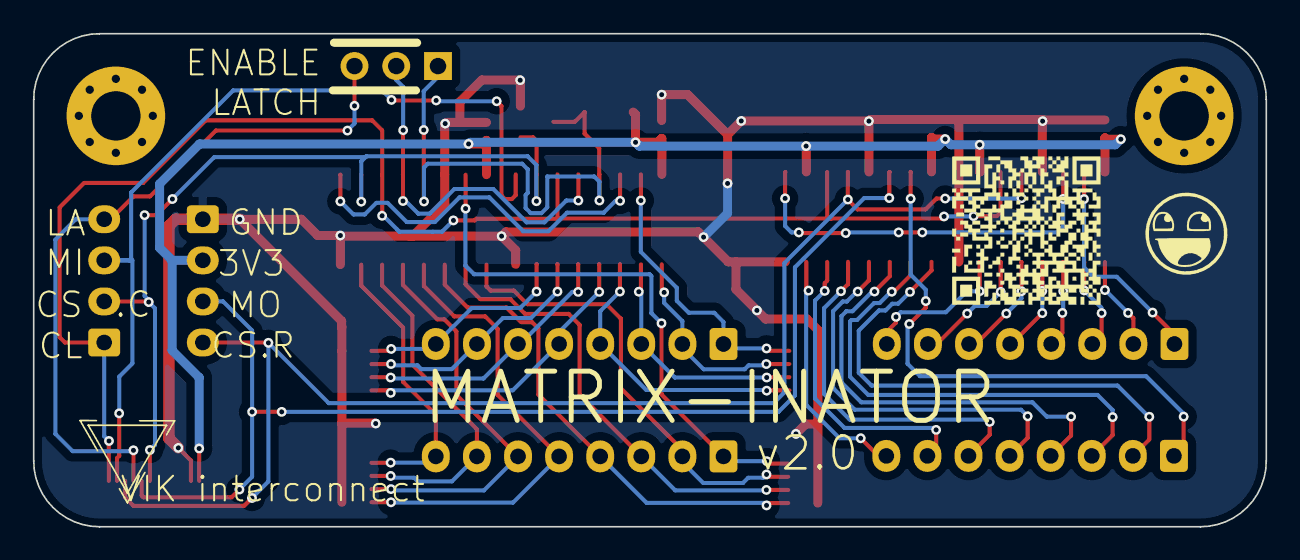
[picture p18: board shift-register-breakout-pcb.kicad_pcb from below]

Board: 2 copper layers, 75.0 x 30.0 mm, 29 parts (3 on the bottom side), 44 nets.

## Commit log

2024-01-07 v1.0 of the breakout board - need to figure out how to properly do logo symbols.
    [shift-register-breakout-pcb.kicad_pcb, shift-register-breakout-pcb.kicad_sch]
2024-01-07 adding text, fixing some errors.
    [shift-register-breakout-pcb.kicad_pcb, shift-register-breakout-pcb.kicad_sch]
2024-01-07 fixing mosfet notes in schematic as per burkfers, final pcb notation added
    [shift-register-breakout-pcb.kicad_pcb, shift-register-breakout-pcb.kicad_sch]
2024-01-07 updating readme with details
    [shift-register-breakout-pcb.kicad_pcb]
2024-03-05 adding latch circuit and resistor arrays
    [shift-register-breakout-pcb.kicad_pcb, shift-register-breakout-pcb.kicad_sch]
2024-03-05 some silkscreen and other changes
    [shift-register-breakout-pcb.kicad_pcb]
2024-03-06 vik-i-fying the design
    [shift-register-breakout-pcb.kicad_pcb, shift-register-breakout-pcb.kicad_sch]
2024-03-06 has been suggested to minimize the design...
    [shift-register-breakout-pcb.kicad_pcb]
2024-03-07 mostly done vik-ifying it
    [shift-register-breakout-pcb.kicad_pcb, shift-register-breakout-pcb.kicad_sch]
2024-03-07 final vik version
    [shift-register-breakout-pcb.kicad_pcb, shift-register-breakout-pcb.kicad_sch]
2024-03-10 almost done readme
    [shift-register-breakout-pcb.kicad_sch]
